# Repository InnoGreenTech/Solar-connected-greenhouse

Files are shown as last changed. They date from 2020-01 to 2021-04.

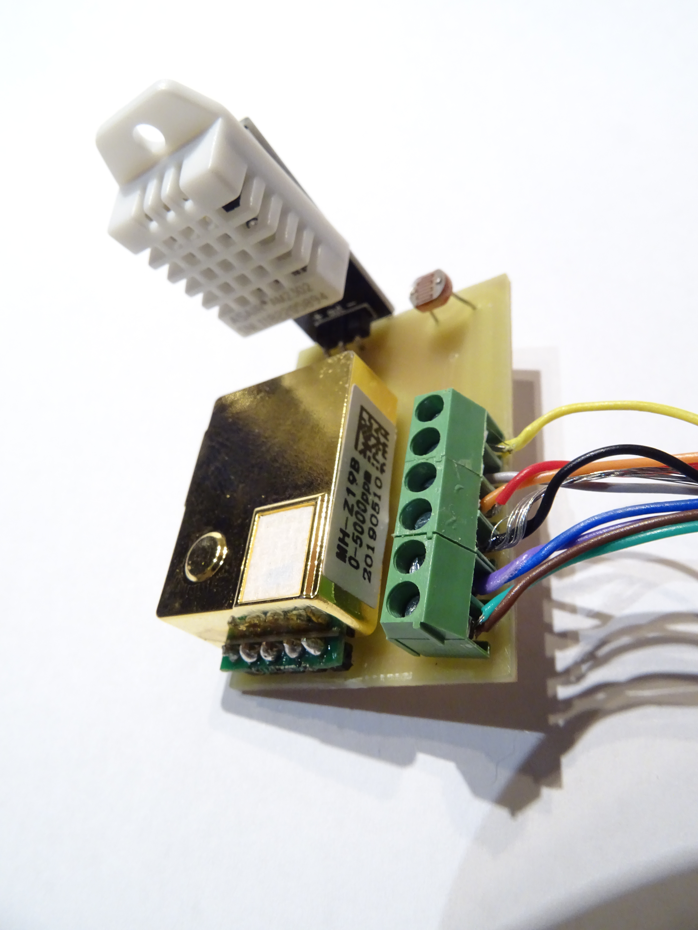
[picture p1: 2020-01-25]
electronic_cards/greenhouse_sensors/DSC01312.JPG

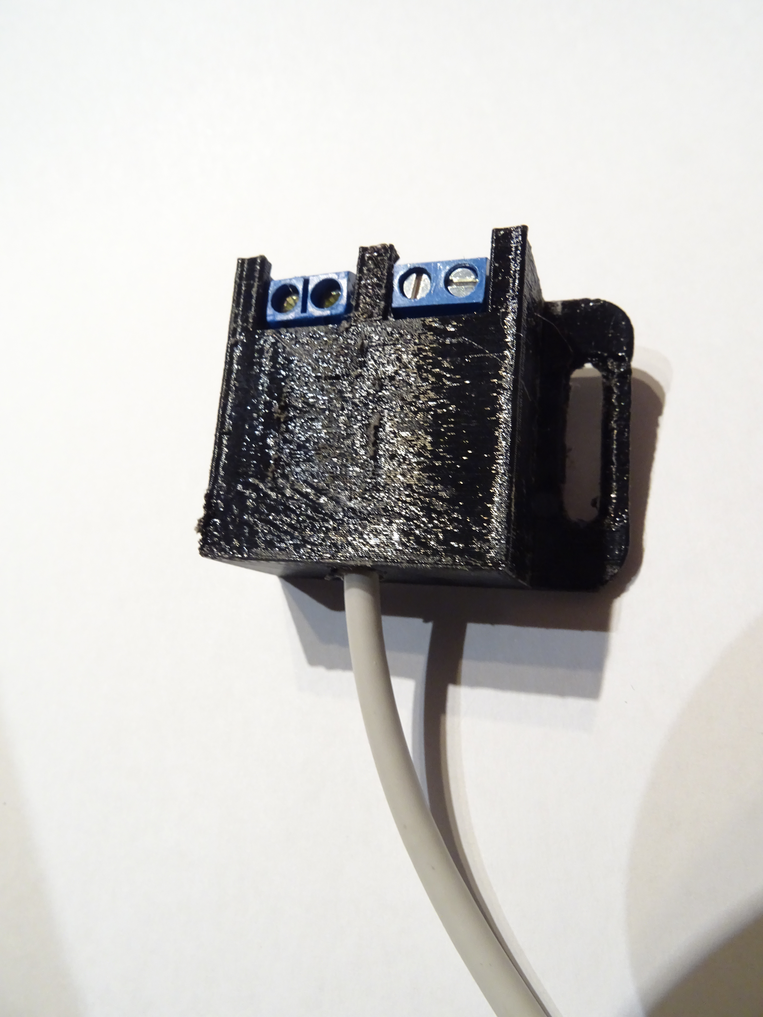
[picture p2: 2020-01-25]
electronic_cards/greenhouse_sensors/DSC01314.JPG

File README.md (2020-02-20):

Solar connected greenhouse
==========================

Description:
------------

This is a autonome greenhouse with solar panels, a tank of water and a composter. It is also possible to control a garden.

This project is building around a Arduino Atmega 2560 and a ESP8266. The ESP8266 is optional, it allows to send data in a Json format. 

There are a lot of functionalities like spray, heating, orthicole lamp, fan, cat proof, … each is power by 24 Vdc provide by the solar pane. It can work with 48 Vdc or relay to work over voltage.

The system can measure humidity, temperature, moisture, CO2, level of water, … in several places. Each data can be send at a data center.

You can find drawing to build the same garden, greenhouse and lombricompost. I have provided the drawings.

There are also any stl files to make boxes for sensors and actuators. 

And the most important the drawings and PCB to make a main board with a
touch screen, a remote for the garden and a remote for the greenhouse.

Statut of project:
-----------------

Sensors of greenhouse:
color:green
1. Temperature
2. Humidity
3. Temperature of soil
4. Humidity of soil
5. Temperature of water
6. Level of water
7. CO2
8. Luminosity
color:black
Sensors of compost:
color:green
1. Temperature compost
2. Humidity compost
3. Voltage battery
4. Intensity battery
5. Intensity Load
color:black
Sensor of garden:
color:green
1. Temperature out
2. Humidity out
3. Temperature soil
4. Humidity soil
color:black
Actuators of greenhouse:
color:green
1. Pump of cooling system
2. Fans of cooling system
3. Fan of VMC
4. Servo motor of VMC clap
5. Horticol lamp
color:black
Actuators of Compost and garden:
color:green
1. Heating compost
2. Main pump spray
3. EV spray Green house
4. EV spray garden
5. EV spray lombric

color:black

[*You can also follow this project here*](http://innogreentech.fr) 

[*A complete description to make electronic boards*](http://innogreentech.fr/en/green-side/green-food/20-serre-connectee/53-electronic-board-for-the-solar-greenhouse)
	electronic boards

[*A dash board to follow my personal project*](http://innogreentech.fr/fr/cote-green/nourriture/serre-et-potager-connectes/45-serre-connectee-en-direct)

Picture of current status

**Contributing**

Fork it
Create your feature branch (git checkout -b my-new-feature)
Commit your changes (git commit -am 'Add some feature')
Push to the branch (git push origin my-new-feature)
Create new Pull Request

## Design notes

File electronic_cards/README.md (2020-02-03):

Electronics cards
==================

Here you can found the drawings and the pcb to make electronics boards.

- Main board
- Remote greenhouse board
- Remoten garden board
- Greenhouse sensors board (for a DHT22, a Photo resistor and a CO2 sensor MH-Z19B)
- Vmc board to connect fan and servo flap

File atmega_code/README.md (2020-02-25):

 /*********************************************************************************************** 
  *                                   output define                                             *
  ***********************************************************************************************/

/* Greenhouse card output*/

    #define GREENHOUSE_VMC           O2_2         
    #define GREENHOUSE_PUMP_COOLING  O2_3
    #define GREENHOUSE_FAN_COOLING   O2_4
    #define GREENHOUSE_LAMP          O2_1
    #define GREENHOUSE_HEATING       O2_0  
    #define GREENHOUSE_HUMIDIFICATOR O2_5
    #define GREENHOUSE_SERVO_VMC     O2_6 

/* Garden card output*/

    #define GARDEN_MAIN_PUMP        O1_0
    #define EV_GARDEN_SPRAY         O1_1
    #define EV_GREENHOUSE_SPRAY     O1_5
    #define EV_COMPOST_SPRAY        O1_4
    #define COMPOST_HEATING         O1_3
    #define COMPOST_DRAIN_PUMP      O1_2

 /*********************************************************************************************** 
  *                                   sensors define                                            *
  ***********************************************************************************************/

  /* Greenhouse sensors*/

    DHT greenhouse_dht(I2_0,DHT22);     // Sensor for humidity and temperature
    
    #define V_BATTERY             A2_4
    #define MOISTURE_GREENHOUSE   A2_0
    #define LUMINOSITY_GREENHOUSE A2_1
    
    DS18B20 onewire_greenhouse(I2_4);  // define the bus of one Wire of the green_house card
    uint8_t address_soil_greenhouse[] ={ 0x28, 0x2F, 0xBC, 0x79, 0x97, 0x08, 0x03, 0x1F};
    uint8_t address_water_greenhouse[] = { 0x28, 0xBF, 0x7B, 0x79, 0x97, 0x05, 0x03, 0x54};

    //Broches sonar for level of water

    #define   TRIGGER_SONAR   I2_3// Broche TRIGGER
    #define   ECHO_SONAR      I2_2// Broche ECHO
    NewPing   water_level(TRIGGER_SONAR,ECHO_SONAR);

/* Garden and lompricomposte sensors */

    #define MOISTURE_GARDEN     A1_4
    #define INTENSITY_BATTERY   A1_1
    #define INTENSITY_LOAD      A1_2   
    #define CAT_PROOF_DETECT    I1_1

    DS18B20 onewire_garden(I1_4);       //define the bus of the one Wire of the garden
    uint8_t address_soil_garden[] = {  0x28,  0x7D,  0x97,  0x79,  0x97,  0x7,  0x3,  0xCF};

    BME280  compost_sensor;             // BME280 sensor
    BME280  out_sensor;

    /**************************************************
 *    Connected map of composter modul            *
 **************************************************/

    #define RX1   17     //Serial communication Serial2
    #define TX1   16     
    
    #define SCL1  SCL      //I²C BUS
    #define SDA1  SDA
    
    #define A1_0  A6      //Charge battery control
    
    #define A1_1  A7      //Analog input, you can use it like a digital input
    #define A1_2  A8
    #define A1_3  A9
    #define A1_4  A10
    
    #define I1_0  32      //Digital input
    #define I1_1  34
    #define I1_2  36
    #define I1_3  38
    #define I1_4  40
    
    #define O1_0  44      //pwm output connected on a mofset
    #define O1_1  31        //Power output connected on a mofset
    #define O1_2  33
    #define O1_3  29
    #define O1_4  35
    #define O1_5  27
    
    #define O1_6  37    //Output 5 volts, can be use for Servo or Steper
    #define O1_7  25
    #define O1_8  39
    #define O1_9  23
    
    #define O1_10 41   //Output 5 volts

/**************************************************
 *    Connected map of greenhouse modul           *
 **************************************************/
 
    #define RX2   15     //Serial communication Serial3
    #define TX2   14     
    
    #define SCL2  21    //I²C BUS
    #define SDA2  20
    
    #define A2_0  A11    //Charge battery control
    
    #define A2_1  A12    //Analog input, you can use it like a digital input
    #define A2_2  A13
    #define A2_3  A14
    #define A2_4  A15
    
    #define I2_0  22      //Digital input
    #define I2_1  24
    #define I2_2  26
    #define I2_3  28
    #define I2_4  30
    
    #define O2_0  43    //Power output connected on a mofset
    #define O2_1  42
    #define O2_2  45    //Pwm output
    #define O2_3  46    //Pwm output
    #define O2_4  47
    #define O2_5  48
    
    #define O2_6  49    //Output 5 volts, can be use for Servo or Steper
    #define O2_7  50
    #define O2_8  51
    #define O2_9  52
    
    #define O2_10 53   //Output 5 volts

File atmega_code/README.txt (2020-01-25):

Solar connected greenhouse Atmega 2560 Software
===============================================

Liraries use:
-------------

#include <DHT.h>
#include <OneWire.h>
#include <DS18B20.h>
#include <NewPing.h>
#include <printf.h>
#include <registers.h> 
#include <pin_magic.h>
#include <Servo.h>

Library modifications:
----------------------

#include <DS18B20.h>:

The time acquisition is really too long to have a good fluidity, i have desactivate this delay on line 57 and read the last get 
before to do a new one. This is in file DS18B20.
		
	float DS18B20::getTempC() {
    		sendCommand(MATCH_ROM, CONVERT_T, !selectedPowerMode);
    		//delayForConversion(selectedResolution, selectedPowerMode);
    		readScratchpad();
    		uint8_t lsb = selectedScratchpad[TEMP_LSB];
    		uint8_t msb = selectedScratchpad[TEMP_MSB];

    		switch (selectedResolution) {
        		case 9:
            			lsb &= 0xF8;
            			break;
        		case 10:
            			lsb &= 0xFC;
            			break;
        		case 11:
            			lsb &= 0xFE;
            			break;
    			}

    		uint8_t sign = msb & 0x80;
    		int16_t temp = (msb << 8) + lsb;

    		if (sign) {
        		temp = ((temp ^ 0xffff) + 1) * -1;
    		}	
	
	sendCommand(MATCH_ROM, CONVERT_T, !selectedPowerMode);
    	//delayForConversion(selectedResolution, selectedPowerMode);

    	return temp / 16.0;
	}

#include <Servo.h>

This library is include with the IDE Arduino. I use the pin 46 PWM, but the servo.h use the same timer than the PWM. I need to change this. It need to do the modification on the file avr/SevoTimer.h line 39.
I have inverted _timer1 and _timer5

	typedef enum { _timer1, _timer5, _timer3, _timer4, _Nbr_16timers } timer16_Sequence_t;

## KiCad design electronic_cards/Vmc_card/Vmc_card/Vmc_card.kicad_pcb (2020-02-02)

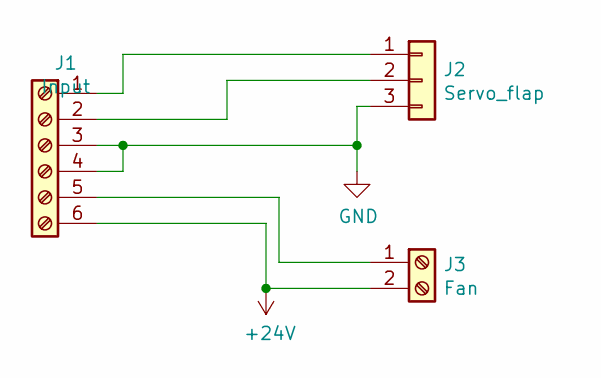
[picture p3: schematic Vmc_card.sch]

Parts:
J1: Input; TerminalBlock_4Ucon_1x06_P3.50mm_Horizontal
J2: Servo_flap; PinHeader_1x03_P2.54mm_Vertical
J3: Fan; TerminalBlock_4Ucon_1x02_P3.50mm_Horizontal

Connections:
+24V: J1.6, J3.2
GND: J1.3, J1.4, J2.3
unnamed: J1.1, J2.1
unnamed: J1.2, J2.2
unnamed: J1.5, J3.1

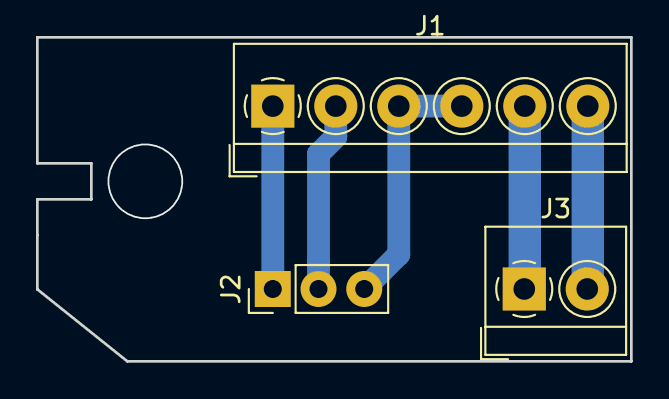
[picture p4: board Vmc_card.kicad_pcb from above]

Board: 2 copper layers, 33.0 x 18.0 mm, 3 parts (0 on the bottom side), 5 nets.

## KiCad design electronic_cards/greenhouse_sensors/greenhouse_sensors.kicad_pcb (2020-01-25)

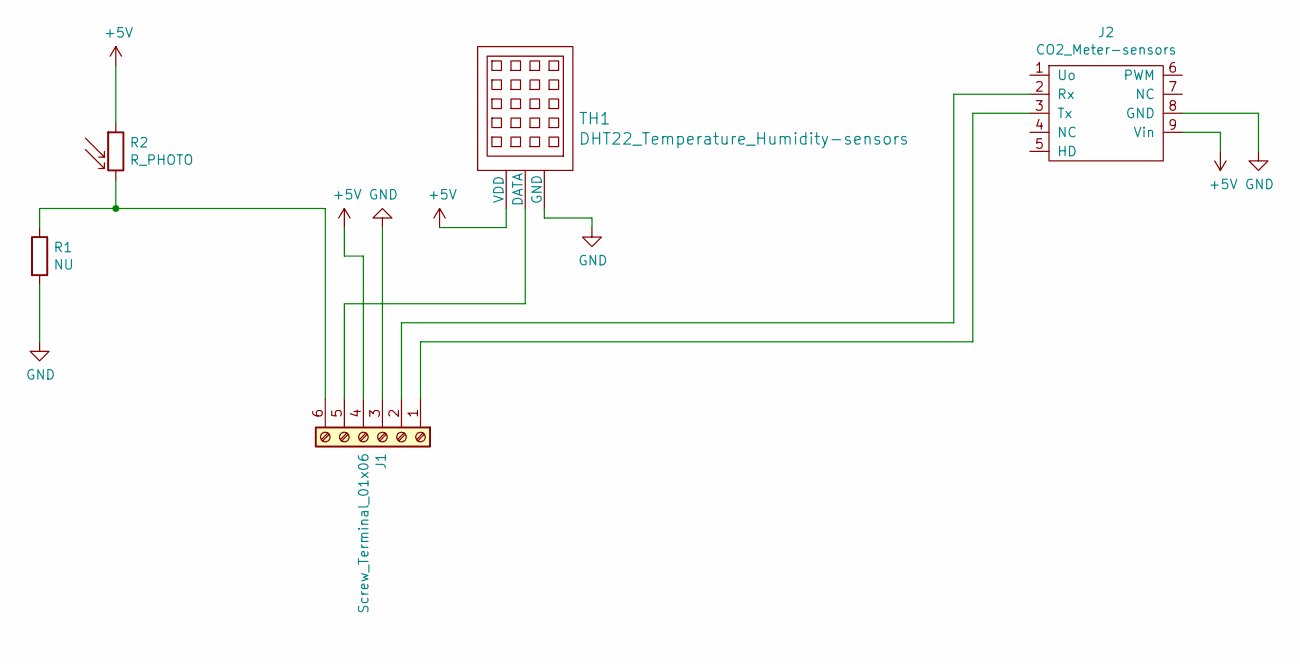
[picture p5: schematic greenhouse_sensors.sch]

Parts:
J1: Screw_Terminal_01x06; TerminalBlock_MetzConnect_Type059_RT06306HBWC_1x06_P3.50mm_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
J2: CO2_Meter-sensors; MHZ19B
R1: NU; R_Axial_DIN0207_L6.3mm_D2.5mm_P7.62mm_Horizontal
R2: R_PHOTO; R_Axial_DIN0204_L3.6mm_D1.6mm_P5.08mm_Vertical
TH1: DHT22_Temperature_Humidity-sensors; DHT22_Temperature_Humidity

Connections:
+5V: J1.4, J2.9 (Vin), R2.1, TH1.1 (VDD)
GND: J1.3, J2.8 (GND), R1.2, TH1.3 (GND)
unnamed: J1.1, J2.3 (Tx)
unnamed: J1.2, J2.2 (Rx)
unnamed: J1.5, TH1.2 (DATA)
unnamed: J1.6, R1.1, R2.2

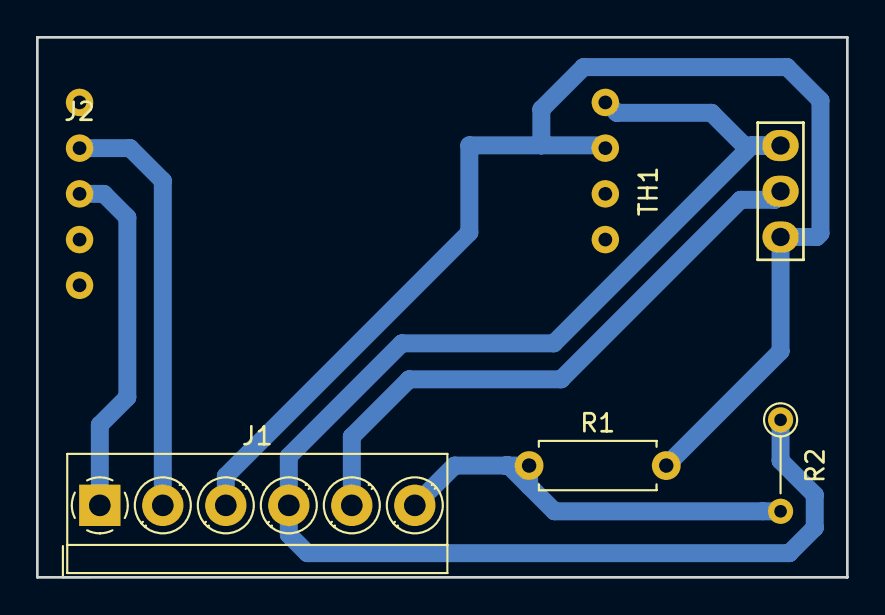
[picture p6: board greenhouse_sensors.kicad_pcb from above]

Board: 2 copper layers, 45.0 x 30.0 mm, 5 parts (0 on the bottom side), 6 nets.

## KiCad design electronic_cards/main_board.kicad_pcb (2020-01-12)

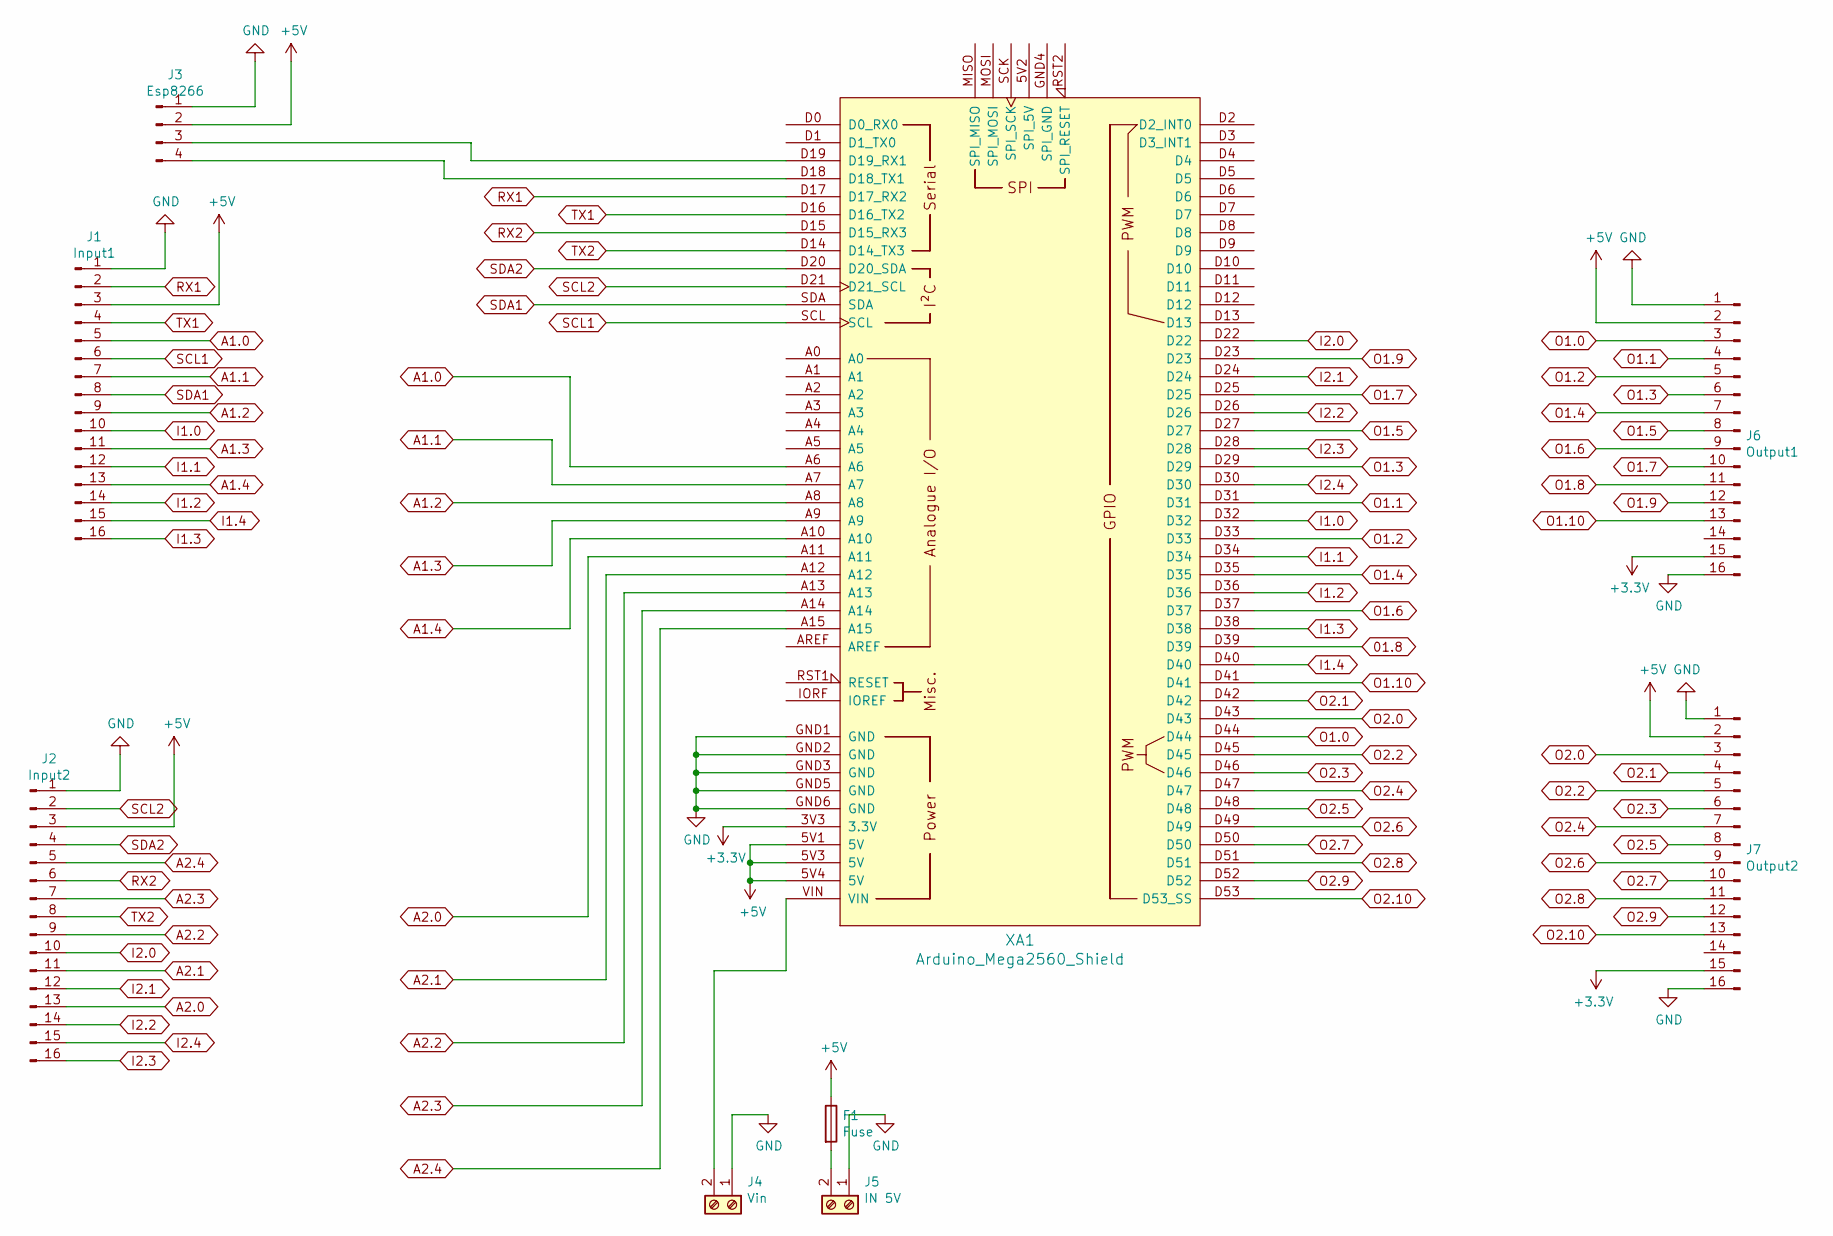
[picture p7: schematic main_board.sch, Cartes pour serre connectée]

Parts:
F1: Fuse; R_Axial_DIN0207_L6.3mm_D2.5mm_P7.62mm_Horizontal
J1: Input1; IDC-Header_2x08_P2.54mm_Vertical
J2: Input2; IDC-Header_2x08_P2.54mm_Vertical
J3: Esp8266; PinHeader_1x04_P2.54mm_Vertical
J4: Vin; SolderWirePad_1x02_P5.08mm_Drill1.5mm
J5: IN 5V; SolderWirePad_1x02_P5.08mm_Drill1.5mm
J6: Output1; IDC-Header_2x08_P2.54mm_Vertical
J7: Output2; IDC-Header_2x08_P2.54mm_Vertical
XA1: Arduino_Mega2560_Shield

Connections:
01.8: XA1.D39
+3V3: J6.15, J7.15, XA1.3V3 (3.3V)
+5V: F1.1, J1.3, J2.3, J3.2, J6.2, J7.2, XA1.5V1 (5V), XA1.5V3 (5V), XA1.5V4 (5V)
A1.0: J1.5, XA1.A6
A1.1: J1.7, XA1.A7
A1.2: J1.9, XA1.A8
A1.3: J1.11, XA1.A9
A1.4: J1.13, XA1.A10
A2.0: J2.13, XA1.A11
A2.1: J2.11, XA1.A12
A2.2: J2.9, XA1.A13
A2.3: J2.7, XA1.A14
A2.4: J2.5, XA1.A15
GND: J1.1, J2.1, J3.1, J4.1, J5.1, J6.1, J6.16, J7.1, J7.16, XA1.GND1 (GND), XA1.GND2 (GND), XA1.GND3 (GND), XA1.GND5 (GND), XA1.GND6 (GND)
I1.0: J1.10, XA1.D32
I1.1: J1.12, XA1.D34
I1.2: J1.14, XA1.D36
I1.3: J1.16, XA1.D38
I1.4: J1.15, XA1.D40
I2.0: J2.10, XA1.D22
I2.1: J2.12, XA1.D24
I2.2: J2.14, XA1.D26
I2.3: J2.16, XA1.D28
I2.4: J2.15, XA1.D30
unnamed: F1.2, J5.2
unnamed: J3.3, XA1.D19 (D19_RX1)
unnamed: J3.4, XA1.D18 (D18_TX1)
unnamed: J4.2, XA1.VIN
O1.0: J6.3, XA1.D44
O1.1: J6.4, XA1.D31
O1.2: J6.5, XA1.D33
O1.3: J6.6, XA1.D29
O1.4: J6.7, XA1.D35
O1.5: J6.8, XA1.D27
O1.6: J6.9, XA1.D37
O1.7: J6.10, XA1.D25
O1.8: J6.11
O1.9: J6.12, XA1.D23
O1.10: J6.13, XA1.D41
O2.0: J7.3, XA1.D43
O2.1: J7.4, XA1.D42
O2.2: J7.5, XA1.D45
O2.3: J7.6, XA1.D46
O2.4: J7.7, XA1.D47
O2.5: J7.8, XA1.D48
O2.6: J7.9, XA1.D49
O2.7: J7.10, XA1.D50
O2.8: J7.11, XA1.D51
O2.9: J7.12, XA1.D52
O2.10: J7.13, XA1.D53 (D53_SS)
RX1: J1.2, XA1.D17 (D17_RX2)
RX2: J2.6, XA1.D15 (D15_RX3)
SCL1: J1.6, XA1.SCL
SCL2: J2.2, XA1.D21 (D21_SCL)
SDA1: J1.8, XA1.SDA
SDA2: J2.4, XA1.D20 (D20_SDA)
TX1: J1.4, XA1.D16 (D16_TX2)
TX2: J2.8, XA1.D14 (D14_TX3)

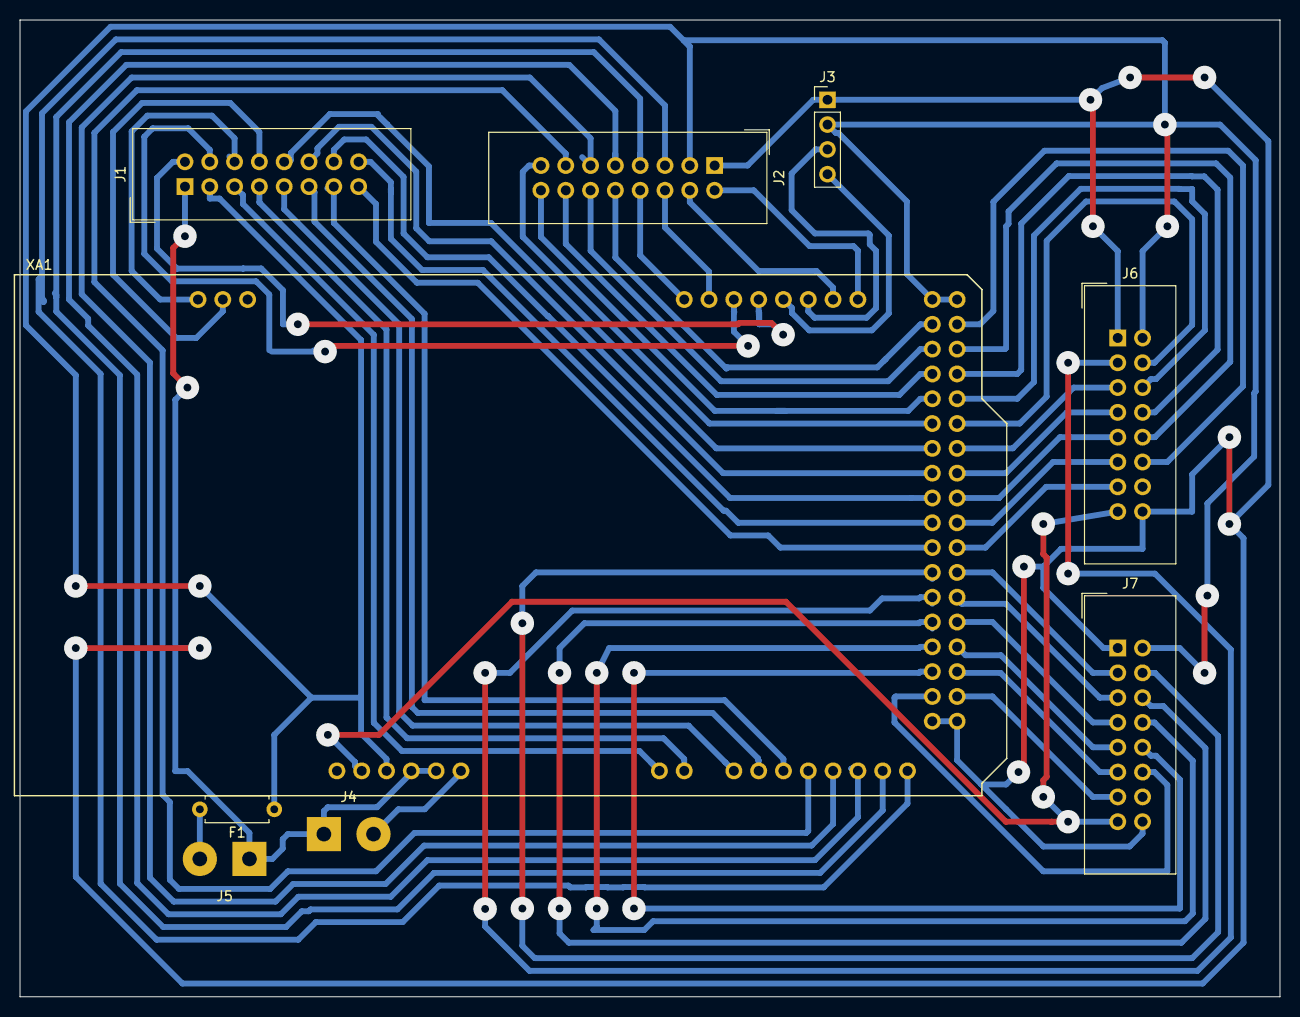
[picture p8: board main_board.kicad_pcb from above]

Board: 2 copper layers, 129.0 x 100.0 mm, 9 parts (0 on the bottom side), 56 nets.

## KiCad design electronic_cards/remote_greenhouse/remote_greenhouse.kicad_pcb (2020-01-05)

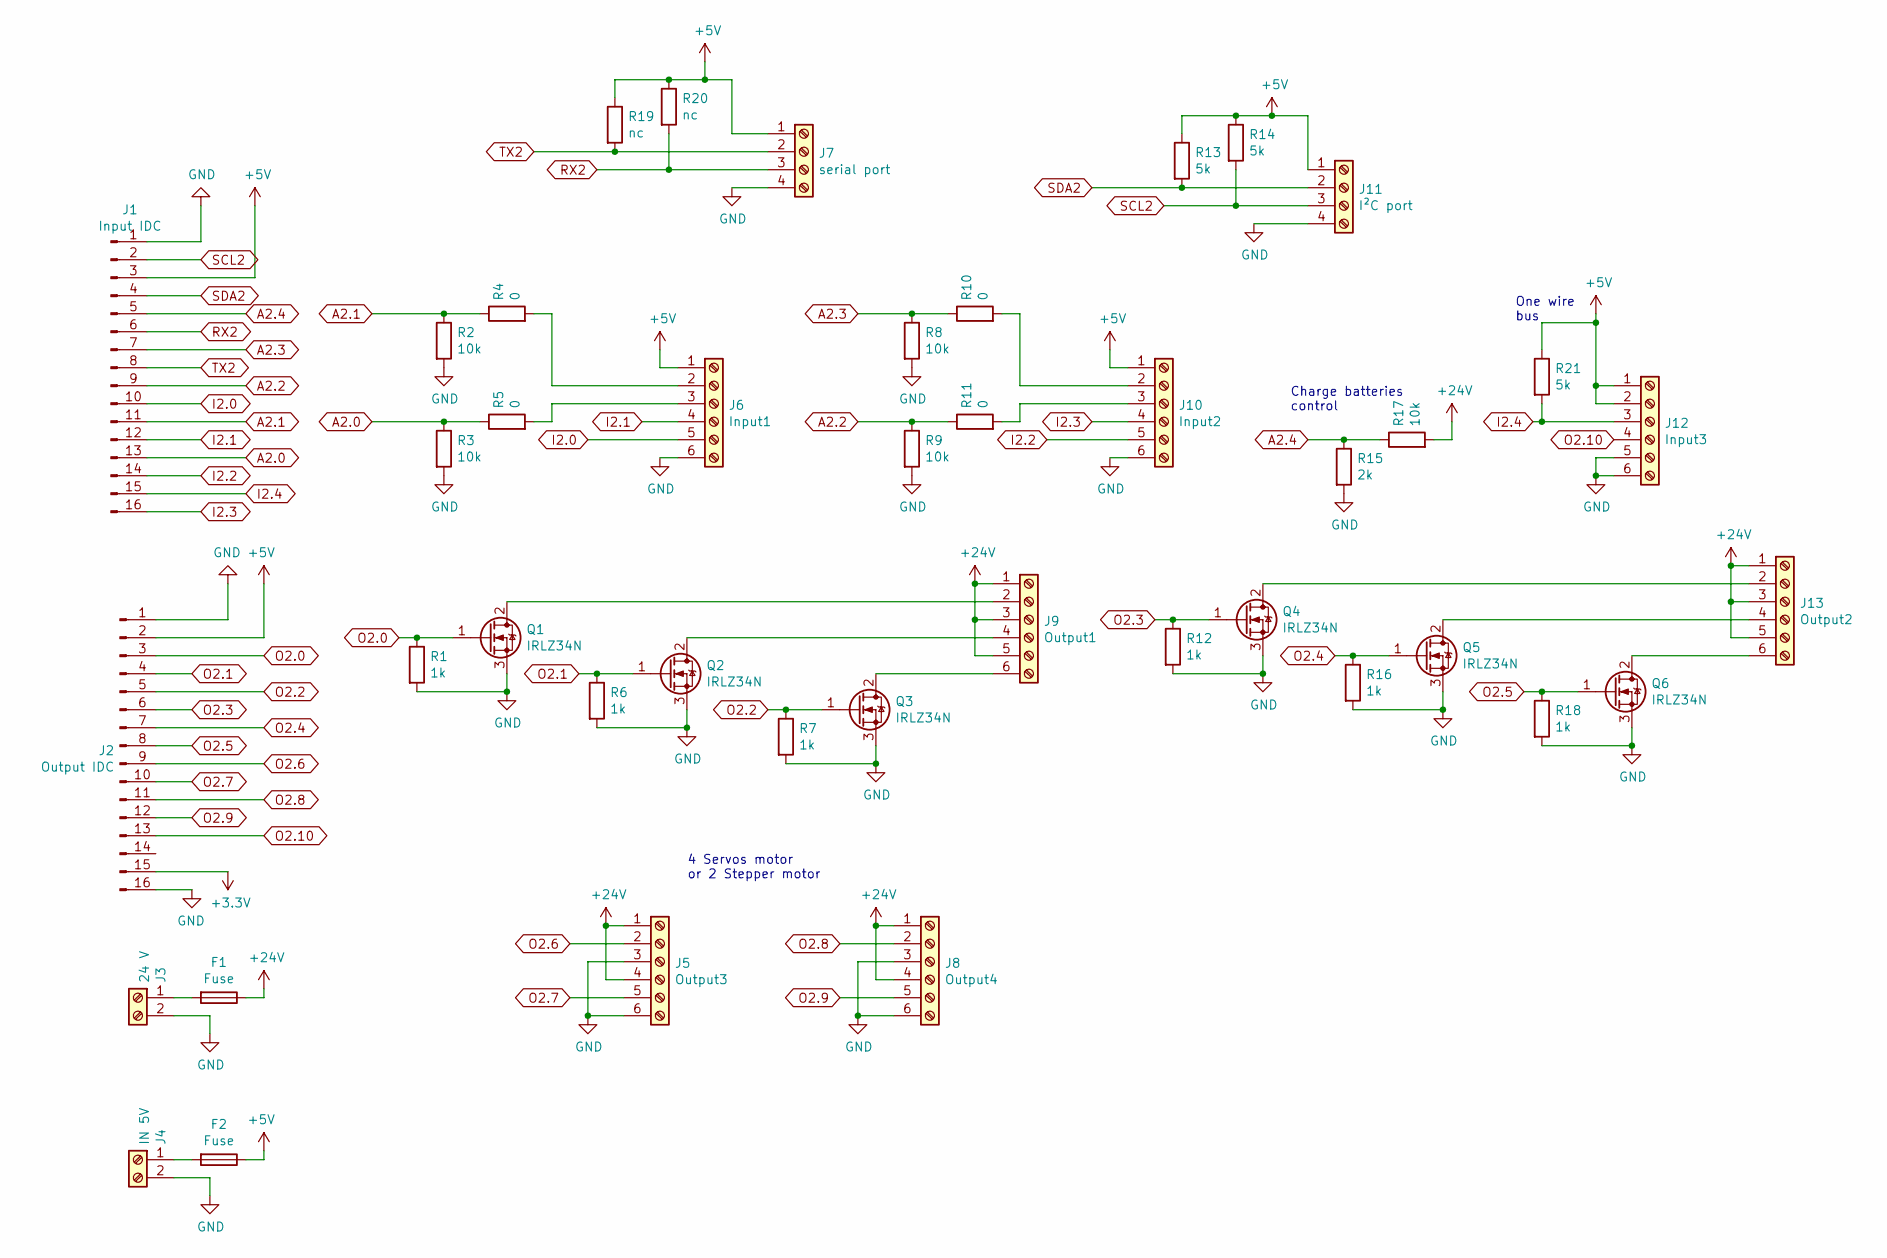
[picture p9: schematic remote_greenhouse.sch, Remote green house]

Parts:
F1, F2: Fuse; Fuse_Littelfuse_395Series
J1: Input IDC; IDC-Header_2x08_P2.54mm_Vertical
J2: Output IDC; IDC-Header_2x08_P2.54mm_Vertical
J3: 24 V; TerminalBlock_MetzConnect_Type101_RT01602HBWC_1x02_P5.08mm_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
J4: IN 5V; TerminalBlock_MetzConnect_Type086_RT03402HBLC_1x02_P3.81mm_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
J5: Output3; TerminalBlock_MetzConnect_Type101_RT01606HBWC_1x06_P5.08mm_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
J6: Input1; TerminalBlock_MetzConnect_Type086_RT03406HBLC_1x06_P3.81mm_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
J7: serial port; TerminalBlock_MetzConnect_Type086_RT03404HBLC_1x04_P3.81mm_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
J8: Output4; TerminalBlock_MetzConnect_Type101_RT01606HBWC_1x06_P5.08mm_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
J9: Output1; TerminalBlock_MetzConnect_Type101_RT01606HBWC_1x06_P5.08mm_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
J10: Input2; TerminalBlock_MetzConnect_Type086_RT03406HBLC_1x06_P3.81mm_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
J11: I²C port; TerminalBlock_MetzConnect_Type086_RT03404HBLC_1x04_P3.81mm_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
J12: Input3; TerminalBlock_MetzConnect_Type086_RT03406HBLC_1x06_P3.81mm_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
J13: Output2; TerminalBlock_MetzConnect_Type101_RT01606HBWC_1x06_P5.08mm_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
Q1, Q2, Q3, Q4, Q5, Q6: IRLZ34N; TO-220-3_Vertical
R1, R6, R7, R12, R16, R18: 1k; R_Axial_DIN0207_L6.3mm_D2.5mm_P7.62mm_Horizontal
R2, R3, R8, R9, R17: 10k; R_Axial_DIN0207_L6.3mm_D2.5mm_P7.62mm_Horizontal
R4, R5, R10, R11: 0; R_Axial_DIN0207_L6.3mm_D2.5mm_P7.62mm_Horizontal
R13, R14, R21: 5k; R_Axial_DIN0207_L6.3mm_D2.5mm_P7.62mm_Horizontal
R15: 2k; R_Axial_DIN0207_L6.3mm_D2.5mm_P7.62mm_Horizontal
R19, R20: nc; R_Axial_DIN0207_L6.3mm_D2.5mm_P7.62mm_Horizontal

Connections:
+3V3: J2.15
+5V: F2.1, J1.3, J2.2, J6.1, J7.1, J10.1, J11.1, J12.1, J12.2, R13.1, R14.1, R19.1, R20.1, R21.1
+24V: F1.1, J5.1, J5.4, J8.1, J8.4, J9.1, J9.3, J9.5, J13.1, J13.3, J13.5, R17.2
A2.0: J1.13, R3.1, R5.1
A2.1: J1.11, R2.1, R4.1
A2.2: J1.9, R9.1, R11.1
A2.3: J1.7, R8.1, R10.1
A2.4: J1.5, R15.1, R17.1
GND: J1.1, J2.1, J2.16, J3.2, J4.2, J5.3, J5.6, J6.6, J7.4, J8.3, J8.6, J10.6, J11.4, J12.5, J12.6, Q1.3 (S), Q2.3 (S), Q3.3 (S), Q4.3 (S), Q5.3 (S), Q6.3 (S), R1.2, R2.2, R3.2, R6.2, R7.2, R8.2, R9.2, R12.2, R15.2, R16.2, R18.2
I2.0: J1.10, J6.5
I2.1: J1.12, J6.4
I2.2: J1.14, J10.5
I2.3: J1.16, J10.4
I2.4: J1.15, J12.3, R21.2
unnamed: F1.2, J3.1
unnamed: F2.2, J4.1
unnamed: J6.2, R4.2
unnamed: J6.3, R5.2
unnamed: J9.2, Q1.2 (D)
unnamed: J9.4, Q2.2 (D)
unnamed: J9.6, Q3.2 (D)
unnamed: J10.2, R10.2
unnamed: J10.3, R11.2
unnamed: J13.2, Q4.2 (D)
unnamed: J13.4, Q5.2 (D)
unnamed: J13.6, Q6.2 (D)
O2.0: J2.3, Q1.1 (G), R1.1
O2.1: J2.4, Q2.1 (G), R6.1
O2.2: J2.5, Q3.1 (G), R7.1
O2.3: J2.6, Q4.1 (G), R12.1
O2.4: J2.7, Q5.1 (G), R16.1
O2.5: J2.8, Q6.1 (G), R18.1
O2.6: J2.9, J5.2
O2.7: J2.10, J5.5
O2.8: J2.11, J8.2
O2.9: J2.12, J8.5
O2.10: J2.13, J12.4
RX2: J1.6, J7.3, R20.2
SCL2: J1.2, J11.3, R14.2
SDA2: J1.4, J11.2, R13.2
TX2: J1.8, J7.2, R19.2

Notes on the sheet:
Charge batteries control
4 Servos motor or 2 Stepper motor
One wire bus

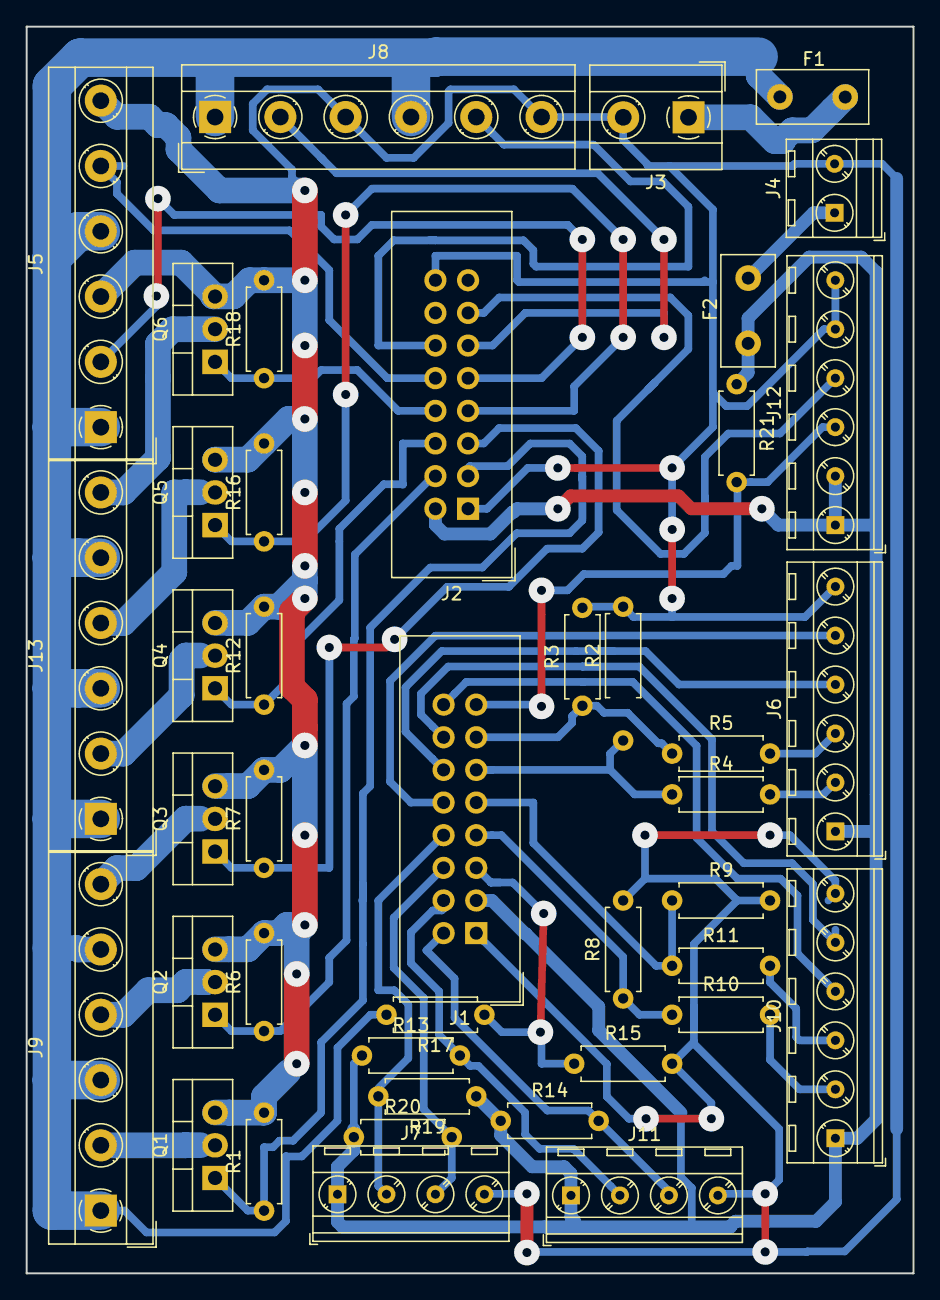
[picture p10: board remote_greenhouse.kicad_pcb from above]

Board: 2 copper layers, 69.0 x 97.0 mm, 42 parts (0 on the bottom side), 40 nets.

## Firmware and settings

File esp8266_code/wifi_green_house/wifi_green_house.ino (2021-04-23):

/************************************************************************************
    
    <Automatic greenhouse and greengarden control,>
    Copyright (C) <2019>  <Fabrice BAUDIN>

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
    info@innogreentech.fr

****************************************************************************************/


/*******************************
 *    utilities                *
 *******************************/
 
 
    #include <ESP8266WiFi.h>          //https://github.com/esp8266/Arduino
    #include <wchar.h> 
    #include <WString.h>
    #include <ESP8266WebServer.h>
    #include <DNSServer.h>
    #include <ESP8266Ping.h>
    #include <ESP8266HTTPClient.h>
    #include <ESP8266HTTPUpdateServer.h>
    
    #include <ArduinoJson.h>
    
    #include <EEPROM.h> // Gestion de la mémoire de type eeprom pour la sauvegarde des choix
    
    #define MEM_NAME_MODULE     1   //Name of module
    #define MEM_ADRESS_SERVER   22  // adress of server php
    #define MEM_PORT_SERVER     43  // Port of server
    #define MEM_PERIOD          50  // Period to send datas in seconds
    #define MEM_SSID            70
    #define MEM_PASSWORD        170 //



/****************************************************** 
 *      Keys of communication with ESP8266            *
 ******************************************************/

    #define CODE_COMMAND_INFO                           "$I$"
    #define CODE_COMMAND_READ                           "$R$" 
    #define CODE_COMMAND_WRITE                          "$W$"
     
    
    #define CODE_TEMPERATURE_COMPOST                    10     
    #define CODE_HUMIDITY_COMPOST                       11
    #define CODE_PUMP_HYDROPONIE                        12
    #define CODE_OUT_COOLING                            13
    #define CODE_SETTING_TEMPERATURE_COMPOST            14
    #define CODE_SETTING_HUMIDITY_COMPOST               15 
    #define CODE_ECO_TEMPERATURE_COMPOST                16
    #define CODE_SPRAY_COMPOST                          17
    #define CODE_CLEAN_COMPOST                          18
    #define CODE_OUTPUT_GARDEN                          19
    
    
    #define CODE_TEMPERATURE_OUT                        20
    #define CODE_HUMIDITY_OUT                           21
    #define CODE_LEVEL_WATER_GARDEN                     22
    #define CODE_SPRAY_GARDEN                           23
    #define CODE_TEMPERATURE_SOIL_GARDEN                24
    #define CODE_MOISTURE_GARDEN                        25
    #define CODE_SETTING_MOISTURE_GARDEN                26
    #define CODE_LUMINOSITY_GREENHOUSE                  27   
    #define CODE_PRESSURE_OUT                           28
    #define CODE_SETTING_ALTITUDE                       29
    #define CODE_HEAT_TANK_WATER                        13
    
    #define CODE_TEMPERATURE_GREENHOUSE                 30
    #define CODE_HUMIDITY_GREENHOUSE                    31
    #define CODE_CO2_GREENHOUSE                         32
    #define CODE_LEVEL_WATER_GREENHOUSE                 33
    #define CODE_SPRAY_GREENHOUSE                       34
    #define CODE_LAMP_GREENHOUSE                        35
    #define CODE_HEAT_TANK_WATER                        36
    #define CODE_FAN_COOLING_GREENHOUSE                 37
    #define CODE_PUMP_COOLING_GREENHOUSE                38
    #define CODE_TEMPERATURE_WATER_GREENHOUSE           39
    #define CODE_TEMPERATURE_SOIL_GREENHOUSE            40
    #define CODE_MOISTURE_GREENHOUSE                    41
    #define CODE_VMC_GREENHOUSE                         42
    #define CODE_FLAP_VENTILATION_GREENHOUSE            43
    #define CODE_HUMIDIFICATOR_GREENHOUSE               44
    #define CODE_SETTING_MOISTURE_GREENHOUSE            45
    #define CODE_SETTING_TEMPERATURE_SOIL_GREENHOUSE    46
    #define CODE_SETTING_HUMIDITY_GREENHOUSE            47
    #define CODE_SETTING_CO2_GREENHOUSE                 48
    #define CODE_OUTPUT_GREENHOUSE                      49
    
    #define CODE_DATE                                   50
    #define CODE_HEURE                                  51
    #define CODE_IP                                     52
    #define CODE_GATE_WAY                               53
    #define CODE_MAC                                    54
    #define CODE_PERIOD_SEND                            55
    
    #define CODE_AVERAGE_V_BATTERY                      60
    #define CODE_GENERAL_PUMP                           61
    #define CODE_AVERAGE_A_BATTERY                      62
    #define CODE_AVERAGE_A_LOAD                         63
    #define CODE_SETTING_V_OFFSET_BATTERIE              64
    #define CODE_SETTING_A_OFFSET_BATTERIE              65
    #define CODE_SETTING_A_OFFSET_LOAD                  66
    #define CODE_SETTING_CAPACITY_BATTERIE              67

    #define CODE_SPRAY_OUT_GARDEN                       70


/**************************************************
 *                RAM Memory map                  *
 **************************************************/

/*input Modul Compost/garden*/

    float   temperature_compost;
    int     humidity_compost;
    int     pressure_compost=1000;
    
    float   a_battery;
    float   average_a_battery;
    float   a_load;
    float   average_a_load;
    float   v_battery;
    float   average_v_battery;
    
    float   temperature_out;
    int     humidity_out;
    int     pressure_out;
    int     moisture_garden;
    float   temperature_soil_garden;
    int     level_water_garden;
    byte    cat_proof;

/*input modul greenhouse*/

    float   temperature_greenhouse;
    int     humidity_greenhouse;
    int     level_water_greenhouse;
    float   temperature_water_greenhouse;
    float   temperature_soil_greenhouse;
    int     moisture_greenhouse;
    int     co2_greenhouse;
    int     luminosity_greenhouse;
     


/* output modul greenhouse*/

    byte    output_greenhouse=0;          
    byte    forced_greenhouse=0;                  // control if the forced mode is activate
    byte    desactive_greenhouse=0;

    //unsigned int time_heat_greenhouse;
    unsigned int time_fan_cooling_greenhouse;
    unsigned int time_pump_cooling_greenhouse;
    unsigned int time_spray_greenhouse;
    unsigned int time_vmc_greenhouse;
    unsigned int time_lamp_greenhouse;
    unsigned int time_humidificator_greenhouse;
    unsigned int time_heat_water_tank;
    
    int          flap_ventilation_greenhouse;

    //unsigned int time_heat_greenhouse_1;
    unsigned int time_fan_cooling_greenhouse_1;
    unsigned int time_pump_cooling_greenhouse_1;
    unsigned int time_spray_greenhouse_1;
    unsigned int time_vmc_greenhouse_1;
    unsigned int time_lamp_greenhouse_1;
    unsigned int time_humidificator_greenhouse_1;
    unsigned int time_heat_water_tank_1;
    
/* output modul garden mode */

    byte    output_garden=0;                   // a bit by output tor
    byte    forced_garden=0;
    byte    desactive_garden=0;

    unsigned int time_main_pump=0;
    unsigned int time_spray_compost=0;
    unsigned int time_heat_tank_water=0;
    unsigned int time_pump_hydroponie=0;
    unsigned int time_spray_garden=0;
    unsigned int time_spray_out_garden=0;
    unsigned int time_out_cooling;

    unsigned int time_main_pump_1=0;
    unsigned int time_spray_compost_1=0;
    unsigned int time_heat_tank_water_1=0;
    unsigned int time_pump_hydroponie_1=0;
    unsigned int time_spray_garden_1=0;
    unsigned int time_spray_out_garden_1=0;
    unsigned int time_out_cooling_1=0;
    
/* String for commnunication */

    String  date;             
    String  currently_time;            
    String  gate_way; 
 



/**************************************************
 *                RAM Memory for setting          *
 **************************************************/


    int     set_temperature_compost;
    int     set_eco_temperature_compost;
    int     set_humidity_compost; 
    int     set_moisture_garden;
    int     set_moisture_greenhouse;
    int     set_temperature_soil_greenhouse;
    int     set_temperature_greenhouse;
    int     set_humidity_greenhouse;
    int     set_co2_greenhouse;
    int     set_v_offset_battery;
    int     set_a_offset_load;
    int     set_a_offset_battery; 
    int     set_capacity_battery;
    int     set_max_intensity;
    int     set_luminosity;
    int     set_deep_water;
    
    int     setting;


 

    int           period;                   // period to sent datas at server
    unsigned long delay_sent;               // delay to send a new message in milliseconds
    unsigned long last_message;
    int           index_average;

    int index_sent=0;                           //allow to sent data one by one with PERIOD_SENT bettween each
    #define PERIOD_SENT 1000                     //one information every 100 ms;
    unsigned long period_sent=0;                //control the last message
    unsigned long number_of_samples;            //Number of samples between two sender 

    
    
    
    char          name_module[20];          // name of module
    String        ref_module;               // référence du module
    String        version_module;           // version of module
    char          ip_server[15];            // adress ip of the module
    int unsigned  port_server;              // port of server
    String        local_mac;                // adress mac of the module
    String        local_ip;                 // adress ip of module


    String        read_mem;                 // Variable pour la réception sur le port série
    int           code;                     // Variable code pour l'échange d'information
    
    
    
    ESP8266WebServer server(80); 
    
    String      ssid="";
    String      password="";
    
    #include    <TimeLib.h>              // Use for take date in internet
    #include    <NtpClientLib.h>

/* setting to update server */

    const char* update_path = "/firmware";
    const char* update_username = "innogreentech";
    const char* update_password = "innogreentech";
    
    ESP8266HTTPUpdateServer httpUpdater;

void setup() {

              Serial.begin(115200);
              Serial.setDebugOutput(0);
              delay(10);
              Serial.println("");
              /* Read EEPROM */
            
              EEPROM.begin(256);                             
             
              
              char carac='1';   // Name of module
              int a=0;
              String read_mem="";
              while (!(carac=='\0')&&a<20){carac=char (EEPROM.read(MEM_NAME_MODULE+a));read_mem+= carac; a++;} 
              if ( a==20){read_mem=F("InnoGreenTech");}
              int c = read_mem.length() + 1;                               // longueur de la chaîne de caractéres
              read_mem.toCharArray(name_module, c); 
             // Serial.println(name_module);        
              
              read_mem="";    // read memory ip adress server
              carac='1';
              a=0;
              while (!(carac=='\0')&&a<20){carac=char (EEPROM.read(MEM_ADRESS_SERVER+a));read_mem+= carac; a++;}
              if (a==20){read_mem=F("InnoGreenTech");} 
              c = read_mem.length() + 1;       
              read_mem.toCharArray(ip_server, c);
              //  Serial.println(ip_server);     

                         
              byte mem[2];
              for (int a=0;a<3;a++){mem[a]= EEPROM.read(MEM_PORT_SERVER+a);}     // load the port server         
              port_server= mem[0]|mem[1]<<8;
              
              for (int a=0;a<3;a++){mem[a]= EEPROM.read(MEM_PERIOD+a);}          // load the time period
              period= mem[0]|mem[1]<<8;
              delay_sent=period*1000;

              carac='1';                
              a=0;
              while (!(carac=='\0')&&a<100){carac=char (EEPROM.read(MEM_SSID+a));
              if (!(carac=='\0')){ssid +=carac;} a++;}  //récupération du lien d'information
              if (ssid=='\0'||a>50){ssid=F("");}
            
              carac='1';
              a=0;
              while (!(carac=='\0')&&a<100){carac=char (EEPROM.read(MEM_PASSWORD+a));
              if (!(carac=='\0')){password +=carac;} a++;}  //récupération du lien d'information
              if (password=='\0'||a>50){password=F("");}




           /*Connexion wifi*/
           
           WiFi.mode(WIFI_STA);
           
           c =ssid.length()+1;
           char char_ssid[50];
           ssid.toCharArray(char_ssid, c);

           c =password.length()+1;
           char char_password[50];
           password.toCharArray(char_password, c);

        
           WiFi.begin(char_ssid,char_password);
           
             unsigned long time_out_connection = millis();
              while (WiFi.status() != WL_CONNECTED)
              {
                if (millis() - time_out_connection > 20000)
                {
                  Serial.println F("");
                  Serial.println F ("connection Wifi fail !");
            
                  break;
                }
                delay(100);
                Serial.print('-');
              }
           
           if ( WiFi.status()!= WL_CONNECTED)
        
              {
                Serial.println F ("Open setting gate !");
                WiFi.disconnect();
                WiFi.mode(WIFI_AP); 
                delay(200);
                WiFi.softAP("InnoGreenTech", "innogreentech");
                server.on ( "/index.html", handleRoot );    // go to set up wifi page
                delay(100);
                server.on ("/style.css", cssRoot);     // envoi au fichier de configuration de style
                local_mac = WiFi.macAddress();
                delay(100);
                server.begin();

              
              }

             else

             {
           
              
              /*Read the hour and date on internet */
            
              NTP.begin("pool.ntp.org", 1, true);  //configuration de la récupération de la date,  Serveur+1 heure, Heure été/hivers
              NTP.setInterval(3600);                // Toutes les heures
                      
              /*information of module*/

              local_ip=WiFi.localIP().toString().c_str();              
              local_mac=WiFi.macAddress();//.toString().c_str();
              gate_way=WiFi.gatewayIP().toString().c_str();
              ref_module="Greenhouse";
              version_module="V1";

              Serial.print(F("référence:"));Serial.println(ref_module);
              Serial.print(F("Version:"));Serial.println(version_module);
              Serial.print(F("Adresse IP:"));Serial.println(local_ip);
              Serial.print(F("Adresse MAC:"));Serial.println(local_mac); 
              Serial.println(WiFi.gatewayIP());
              Serial.println(WiFi.dnsIP(1));             
                    
                          
              /* setting of web server */
              
              server.on ( "/index.html", indexRoot );    // Renvoi à la page de index
               delay(100);
              server.on ( "/", indexRoot );    // Renvoi à la page de index
              delay(100);
              server.on ( "/add_module.csv", add_module );    // Page for add or modify  module by php server 
              delay(100);
              server.on ("/style.css", cssRoot);     // envoi au fichier de configuration de style
              delay(100);
               
              httpUpdater.setup(&server, update_path, update_username, update_password);
             }
              
              /*listen the server*/
              
              server.begin();

              
              }


void loop() {

            server.handleClient();
            recep_data();
            send_information();
            if (millis()>last_message+delay_sent){send_data();}
  
            }

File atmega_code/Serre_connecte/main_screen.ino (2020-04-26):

/*********************************
*             Page d'accueil     *
**********************************/

void main_screen(){


/*********************************************************
*                  Back screen                           *
**********************************************************/


if (!bitRead(flag_first_screen,MAIN_SCREEN)){

  
  tft.fillScreen(FOND); 
  tft.drawFastVLine(160,10,160,WHITE);
  tft.drawFastHLine(180,105,120,WHITE);
  tft.setTextSize(2); 
  tft.setTextColor(GREEN); 
  tft.setCursor(50,10);                     // Describe content
  tft.print F("SERRE");
  //tft.setTextColor(CYAN);
  //tft.setCursor(185,10);
  //tft.print F("JARDINIERE");
  tft.setTextColor(YELLOW);
  tft.setCursor(195,115);
  tft.print F("COMPOSTE");
  
  
  tft.setTextSize(1); 
  tft.setTextColor(WHITE);
  tft.setCursor(10,50); 
  tft.print F("Temperature air:");
  tft.setCursor(10,65);
  tft.print F("Humidite air:");  
  tft.setCursor(10,85);
  tft.print F("Temperature sol:");
  tft.setCursor(10,100);
  tft.print F("Humidite sol:");
  tft.setCursor(10,120);
  tft.print F("Temperature eau:");
  tft.setCursor(10,135);
  tft.print F("Niveau eau:");
  tft.setCursor(10,155);
  tft.print F("Tension batterie:");
  

  tft.setCursor(175,50); 
  tft.print F("Temperature ext:");
  tft.setCursor(175,65);
  tft.print F("Humidite ext:");  
  tft.setCursor(175,85);
  tft.print F("Humidite sol:");

  tft.setCursor(175,145); 
  tft.print F("Temperature:");
  tft.setCursor(175,160);
  tft.print F("Humidite:");  






/* Write Bottons */
      main_buttons_design();

bitSet(flag_first_screen,MAIN_SCREEN); 

    } 



/****************************************************
 *                Write  information                *
 ****************************************************/

if(bitRead(refresh_demand,REFRESH_SCREEN)){


  tft.setFont(&Weathericon);
  tft.setTextSize(2);
  tft.setTextColor(WHITE,FOND);
  tft.setCursor(200,45);
 /* tft.setTextSize(2); 
  tft.setTextColor(CYAN,FOND); 
  tft.setCursor(175,5);
  tft.print (weather_string[current_weather-1]);   
  tft.setTextColor(ORANGE,FOND); 
  tft.setCursor(175,25);*/
  tft.print (weather_string[forecasts_weather-1]);
  
  tft.setFont();
  tft.setTextSize(1); 
  tft.setTextColor(GREEN,FOND);
  tft.setCursor(110,50);
  tft.print (temperature_greenhouse,2);
  tft.print F(" C ");
  tft.setCursor(110,65);
  tft.print (humidity_greenhouse,1);
  tft.print F(" % ");  
  
  tft.setCursor(110,85);
  tft.print (temperature_soil_greenhouse,2);
  tft.print F(" C ");
  tft.setCursor(110,100);
  tft.print (moisture_greenhouse);
  tft.print F(" % ");
  tft.setCursor(110,120);
  tft.print (temperature_water_greenhouse,2);
  tft.print F(" C ");
  tft.setCursor(110,135);
  tft.print (level_water_greenhouse,1);
  tft.print F(" Cm ");
  tft.setCursor(110,155);
  tft.print (v_battery,2);
  tft.print F(" V ");

  tft.setCursor(270,50); 
  tft.print (temperature_out,2);
  tft.print F(" C ");
  tft.setCursor(270,65);
  tft.print (humidity_out);
  tft.print F(" % ");  
  tft.setCursor(270,85);
  tft.print (moisture_garden);
  tft.print F(" % ");


  tft.setCursor(270,145);
  tft.print (temperature_compost,2); 
  tft.print F(" C ");
  tft.setCursor(270,160);
  tft.print (humidity_compost);
  tft.print F(" % ");  

  tft.setCursor(280,10);
  tft.print (pressure_corrected,0);   
  tft.setCursor(280,30);
  tft.print ("mb");
  
} 
/***********************************************************************************************************************************  
* Access to Greenhouse screen 
*/
  
  if(four_buttons[GREENHOUSE].contains(x,y))
    { 
      flag_screen=0;  
      flag_first_screen=0;
      refresh_demand=2;
      bitSet(flag_screen,GREENHOUSE_SCREEN); 
    }

/**************************************************************************************************************************************  
*  Access to compost screen
 */
 
  if (four_buttons[COMPOST].contains(x,y))
    {    
      flag_screen=0;  
      flag_first_screen=0;
      refresh_demand=2;
      bitSet(flag_screen,COMPOST_SCREEN);
    }
  
/***********************************************************************************************************************************
* Access to Garden screen
*/
 
  if (four_buttons[GARDEN].contains(x,y))
    {   
      flag_screen=0;
      refresh_demand=2;
      flag_first_screen=0;
      bitSet(flag_screen,GARDEN_SCREEN);
    }

/***********************************************************************************************************************************
* Access to Wifi screen
*/
 
  if (four_buttons[INFORMATION].contains(x,y))
    { 
      //Serial.println("demande ecrans");  
      flag_screen=0;  
      flag_first_screen=0;
      refresh_demand=2;
      bitSet(flag_screen,INFORMATION_SCREEN);
    }

   y=0;
   x=0;  
 
}
  

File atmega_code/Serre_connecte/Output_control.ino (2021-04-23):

void output_greenhouse_control(){
  
  if(bitRead(refresh_demand,REFRESH_DATA))
  
     { 
          cooling_control();
          spray_greehouse();
          vmc_control();
          lamp_control();
          heating_water_tank(1);
    }

}

void output_garden_control(){
  if(bitRead(refresh_demand,REFRESH_DATA))
    { 
  
        spray_garden();     
        spray_compost();
        hydroponie_pump();      
        main_pump();
        spray_out_garden();
        out_cooling();
        
    }
}

/* Cooling system */

        void cooling_control(){
        if (!bitRead(desactive_greenhouse,FAN_COOLING_GREENHOUSE))
          { 
            if (bitRead(output_greenhouse,FAN_COOLING_GREENHOUSE)|| bitRead(forced_greenhouse,FAN_COOLING_GREENHOUSE)) 
                    {
                      digitalWrite(GREENHOUSE_FAN_COOLING,1);
                      time_cooling_greenhouse=time_cooling_greenhouse+DELAY_REFRESH_SCREEN_SECONDS;
                    }
            else{digitalWrite(GREENHOUSE_FAN_COOLING,0);}
          }
        else{digitalWrite(GREENHOUSE_FAN_COOLING,0);}
        
        if (!bitRead(desactive_greenhouse,PUMP_COOLING_GREENHOUSE))
          {
            if (bitRead(output_greenhouse,PUMP_COOLING_GREENHOUSE) || bitRead(forced_greenhouse,PUMP_COOLING_GREENHOUSE)) 
                    {
                      analogWrite(GREENHOUSE_PUMP_COOLING,80);                                          
                    }
            else{analogWrite(GREENHOUSE_PUMP_COOLING,0);}
          }
        else{analogWrite(GREENHOUSE_PUMP_COOLING,0);}   
        }
             
/* spray system */

        void spray_greehouse(){
        
        if (!bitRead(desactive_greenhouse,SPRAY_GREENHOUSE))
          {
            if(bitRead(output_greenhouse,SPRAY_GREENHOUSE) || bitRead(forced_greenhouse,SPRAY_GREENHOUSE)){
              digitalWrite(EV_GREENHOUSE_SPRAY,1);
              time_greenhouse_spray=time_greenhouse_spray+DELAY_REFRESH_SCREEN_SECONDS;
              }
            else {digitalWrite(EV_GREENHOUSE_SPRAY,0);} 
          }
        else {digitalWrite(EV_GREENHOUSE_SPRAY,0);}
        }
        
/* VMC control */

        void vmc_control(){
        
        if (!bitRead(desactive_greenhouse,VMC_GREENHOUSE))
          {
            if (bitRead(output_greenhouse,VMC_GREENHOUSE) || bitRead(forced_greenhouse,VMC_GREENHOUSE)){
              digitalWrite(GREENHOUSE_VMC,1);
              time_vmc_greenhouse=time_vmc_greenhouse+DELAY_REFRESH_SCREEN_SECONDS;
            }
            else{digitalWrite(GREENHOUSE_VMC,0);}
          }
        else{digitalWrite(GREENHOUSE_VMC,0);}
        }
        
/* Lamp control */

        void lamp_control(){
        
        if (!bitRead(desactive_greenhouse,LAMP_GREENHOUSE))
          {
            if ((bitRead(output_greenhouse,LAMP_GREENHOUSE)and v_battery>25) || bitRead(forced_greenhouse,LAMP_GREENHOUSE)){
              digitalWrite(GREENHOUSE_LAMP,1);
              time_lamp_greenhouse=time_lamp_greenhouse+DELAY_REFRESH_SCREEN_SECONDS;
            }
            else{digitalWrite(GREENHOUSE_LAMP,0);}
          }
        else{digitalWrite(GREENHOUSE_LAMP,0);}
        }
        
/* heating tank water*/

     void heating_water_tank(int refresh){
            
      if (!bitRead(desactive_greenhouse, HEATING_WATER_TANK))
        {
          if(bitRead(output_greenhouse,HEATING_WATER_TANK) || bitRead(forced_greenhouse,HEATING_WATER_TANK)){
                if(bitRead(forced_greenhouse,HEATING_WATER_TANK)){pwm_heat_water_tank=255;}
                analogWrite(WATER_TANK_HEATING,pwm_heat_water_tank);
                if (refresh=1){time_heat_water_tank=time_heat_water_tank+DELAY_REFRESH_SCREEN_SECONDS;}
                }
          else{analogWrite(WATER_TANK_HEATING,false);}
        }
      else{analogWrite(WATER_TANK_HEATING,false);}
     }

/* Spray garden control */

      void spray_garden(){
      if (!bitRead(desactive_garden,SPRAY_GARDEN))
        {
          if(bitRead(output_garden,SPRAY_GARDEN) || bitRead(forced_garden,SPRAY_GARDEN)|| bitRead(output_garden,CAT_PROOF_GARDEN)){
            digitalWrite(EV_GARDEN_SPRAY,1);
            time_spray_garden=time_spray_garden+DELAY_REFRESH_SCREEN_SECONDS;
            }
          else {digitalWrite(EV_GARDEN_SPRAY,0);}  
        }
      else {digitalWrite(EV_GARDEN_SPRAY,0);} 
      } 
      
/* Compost spray */

      void spray_compost(){
      if (!bitRead(desactive_garden, SPRAY_COMPOST))
        {
          if(bitRead(output_garden,SPRAY_COMPOST) || bitRead(forced_garden,SPRAY_COMPOST)){
            digitalWrite(EV_COMPOST_SPRAY,1);
            time_spray_compost=time_spray_compost+DELAY_REFRESH_SCREEN_SECONDS;
            }
          else {digitalWrite(EV_COMPOST_SPRAY,0);}    
        }
      else {digitalWrite(EV_COMPOST_SPRAY,0);}
      }
      
/* hydroponie pump */

      void hydroponie_pump(){      
      if (!bitRead(desactive_garden, PUMP_HYDROPONIE))
        {
          if(bitRead(output_garden,PUMP_HYDROPONIE) || bitRead(forced_garden,PUMP_HYDROPONIE)){
            analogWrite(HYDROPONIE_PUMP, 120);
            time_pump_hydroponie=time_pump_hydroponie+DELAY_REFRESH_SCREEN_SECONDS;
            }
          else {analogWrite(HYDROPONIE_PUMP, 0);} 
        }
      else {analogWrite(HYDROPONIE_PUMP, 0);}
      }
      

      
/*  main pump control */

      void main_pump(){
      if (!bitRead(desactive_garden, MAIN_PUMP))
        {
          if( digitalRead(EV_GARDEN_SPRAY)|| digitalRead(EV_GREENHOUSE_SPRAY) || digitalRead(EV_COMPOST_SPRAY)){
            digitalWrite(GARDEN_MAIN_PUMP, true);
          }
          else{digitalWrite(GARDEN_MAIN_PUMP,false);}
        }
      else{digitalWrite(GARDEN_MAIN_PUMP,false);}
      }

/* out_garden spray*/

      void spray_out_garden(){
      if (!bitRead(desactive_garden, SPRAY_OUT_GARDEN))
        {
          if(bitRead(output_garden,SPRAY_OUT_GARDEN) || bitRead(forced_garden,SPRAY_OUT_GARDEN)|| bitRead(output_garden,CAT_PROOF_OUT_GARDEN)){
            digitalWrite(OUT_GARDEN_SPRAY,1);
            time_out_garden_spray=time_out_garden_spray+DELAY_REFRESH_SCREEN_SECONDS;
            }
          else {digitalWrite(OUT_GARDEN_SPRAY,0);}    
        }
      else {digitalWrite(OUT_GARDEN_SPRAY,0);}
      }

/* out_cooling to refresh water during the Night*/

      void out_cooling(){
      if (!bitRead(desactive_garden, COOLING_OUT))
        {
          if(bitRead(output_garden,COOLING_OUT) || bitRead(forced_garden,COOLING_OUT)){
            digitalWrite(OUT_COOLING,1);
            time_out_cooling=time_out_cooling+DELAY_REFRESH_SCREEN_SECONDS;
            }
          else {digitalWrite(OUT_COOLING,0);}    
        }
      else {digitalWrite(OUT_COOLING,0);}
      }

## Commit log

2020-01-01 Ajout des fichiers de la photo d'acceuil
2020-01-02 Ajout du fichier de licence
2020-01-04 Create file of the first version of arduino software
2020-01-05 The first version of the wifi connection (not work in the state)
    [main_board.kicad_pcb, main_board.sch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]
2020-01-12 Correctrion of PCB, RX and TX of ESP were inverted
    [main_board.kicad_pcb, main_board.sch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]
2020-01-16 Correction of many bugs on the communication between arduino and esp
    [RecepWifi.ino, ReceptionDonnees.ino, Serre_connecte.ino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]
2020-01-19 Improve communication between Esp and arduino
2020-01-25 befor implement vmc controler
    [Vmc_card.kicad_pcb, Vmc_card.sch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]
2020-02-02 Add Vmc control and remove any bugs
    [Vmc_card.kicad_pcb, Vmc_card.sch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]
2020-02-08 change out sensor by BME280, add setting parameters
2020-02-09 improve measure of intensity and voltage
2020-02-20 change level water sensor
2020-02-25 Add weather forecasts and improve moist sensors. I add 3 parameters , 2 for moisture sensors, and 1 for altitude parameter
2020-03-08 update ESP software to protec wrong sent values
    [ReceptionDonnees.ino, Serre_connecte.ino, garden_gest.ino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]
2020-03-22 add watch dog control and average humidity and temperature day
2020-03-29 Add hydroponie fonctionnality and change probe for compost, use DS18B20 in place of BME 280
2020-05-24 change methode of heating composter, use cooling sytem
2020-06-08 New level water sensor, pressure sensor
2020-07-12 realease a test on the board
2020-07-14 Correction level water with temperature greenhouse
    [Output_control.ino, garden_gest.ino, greenhouse_gest.ino]
2020-08-15 Use water proof sonar for the level of water
2020-09-16 add two fonctionnalities, heat water with solar energy too much, and a cooling water when the weather is too hot
    [Output_control.ino, ReceptionDonnees.ino, Serre_connecte.ino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]
2021-04-23 desable PID , and active intensity to adjust recover power

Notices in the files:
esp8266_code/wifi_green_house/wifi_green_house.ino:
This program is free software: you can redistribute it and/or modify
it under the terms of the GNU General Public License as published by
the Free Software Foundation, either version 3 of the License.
